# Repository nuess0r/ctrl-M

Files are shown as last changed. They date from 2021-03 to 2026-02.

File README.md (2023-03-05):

# Ctrl M Controller for Model M

ctrl-m

This is a replacement controller for the famous IBM Model M keyboard based on the STM32F072 microcontroller. Goal is to get it upstream in QMK.

Work in progress, prototypes are working in Model M from 1989, there is a bug for the version from 1986 and test for other variants are outstanding.

## Hardware

Controller based on a STM32F072 chip and designed with KiCAD.

To make the controller as flexible as possible there are four possible LED and earth cable connectors. Also the PCB can be cut into a smaller variant that fits the later IBM/Lexmark variant.

The four LED connector variants are:

    J8 is a 12 pin connector is mounted for J8 for both LED and keyboard
    J8 is a 8 pin connector and J9 is a 4 pin connector
    J8 is a 8 pin connector and J12 is a 4 pin connector
    J8 is a 8 pin connector and J10 is a 4 pin header

https://github.com/nuess0r/ctrl-M

To fill the gab between the USB connector and the case and also to make it easier to press the bootloader button a small plastic part (button_lever.amf) was designed with FreeCAD that can be 3D printed.

## Software

https://github.com/nuess0r/qmk_firmware/tree/ctrl_m/keyboards/ctrl_m

## Assembly Instructions

https://brain4free.org/wiki/doku.php/elektronik:ctrl_m#assembly_instructions

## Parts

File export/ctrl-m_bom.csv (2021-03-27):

Comment | Designator | Footprint | LCSC
4.7u | C1,C3 | Capacitor_SMD:C_0805_2012Metric
100n | C2,C4,C5,C6,C7 | Capacitor_SMD:C_0603_1608Metric
10n | C8 | Capacitor_SMD:C_0603_1608Metric
MountingHole_Pad | H1,H2 | MountingHole:MountingHole_3.2mm_M3_Pad
MountingHole | H3,H4 | MountingHole:MountingHole_4mm_Pad
USB_B | J1 | Connector_USB:USB_B_OST_USB-B1HSxx_Horizontal
Conn_01x04 | J10 | Connector_PinHeader_2.54mm:PinHeader_1x04_P2.54mm_Horizontal
Conn_01x05 | J11 | Connector_PinHeader_2.54mm:PinHeader_1x05_P2.54mm_Vertical
Conn_01x04 | J9,J12 | Connector_FPC_2.54mm:TE_5-520315-4_1x04_P2.54mm_Vertical
Conn_ARM_JTAG_SWD_10 | J2 | Connector_PinHeader_1.27mm:PinHeader_2x05_P1.27mm_Vertical
Conn_01x01 | J3,J4,J5,J6 | Connector_Blade:Blade_6.3mm_Horizontal
Conn_01x16 | J7 | Connector_FPC_2.54mm:TE_6-520315-6_1x16_P2.54mm_Vertical
Conn_01x12 | J8 | Connector_FPC_2.54mm:TE_6-520315-2_1x12_P2.54mm_Vertical
1k | R1 | Resistor_SMD:R_0603_1608Metric
120 | R2,R3,R4 | Resistor_SMD:R_0603_1608Metric
SW_Push | SW1 | Button_Switch_THT_narrow:SW_SPST_UK_B0205-G4.3-B-250
USBLC6-2SC6 | U1 | Package_TO_SOT_SMD:SOT-23-6
XC6206P332PR | U2 | Package_TO_SOT_SMD:SOT-89-3
STM32F072CBT6 | U3 | Package_QFP:LQFP-48_7x7mm_P0.5mm

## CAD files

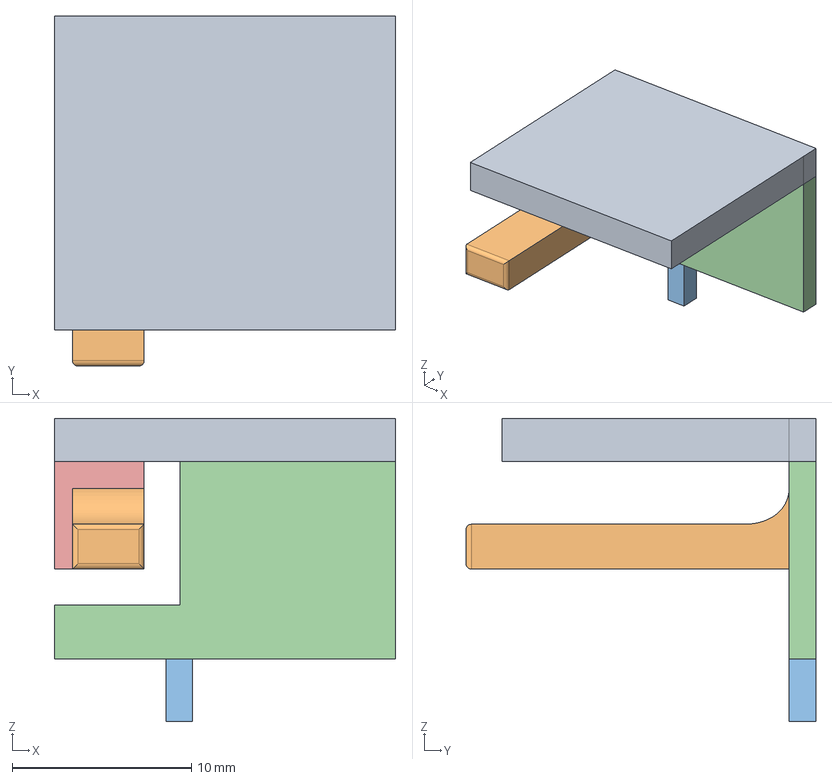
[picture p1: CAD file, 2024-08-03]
export/button_lever.step
19.0 x 19.5 x 16.9 mm

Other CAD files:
button_lever.FCStd
export/button_lever.amf

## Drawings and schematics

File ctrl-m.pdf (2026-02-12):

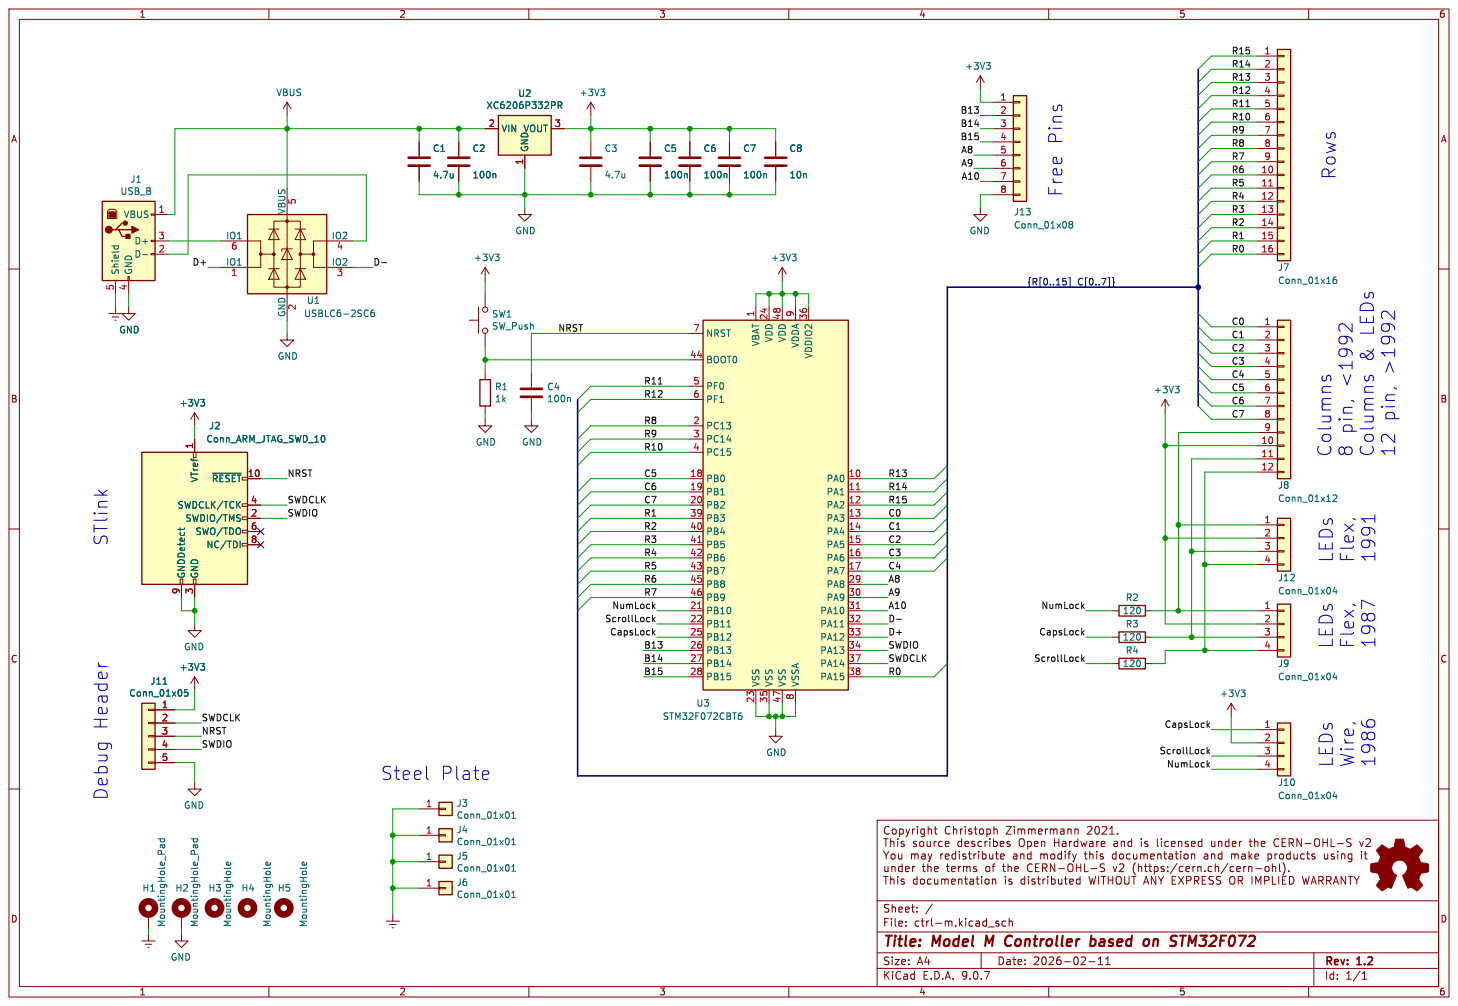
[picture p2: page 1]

& LEDs 12 pin, >1992 LEDs Wire, 1986 Rows Free Pins LEDs Flex, 1991 LEDs Flex, 1987 Debug Header J11 Conn_01x05
B14 STlink

3 ~{RESET}10 SWDCLK/TCK 4 SWDIO/TMS 2 SWO/TDO 6 NC/TDI 8 C2

1 VSS 23 VDD 24 VSS 35 VDD 48 VSS 47 VDDA

3 ~{RESET}10 SWDCLK/TCK 4 SWDIO/TMS 2 SWO/TDO 6 NC/TDI 8

Id: 1/1 Title: Model M Controller based on STM32F072

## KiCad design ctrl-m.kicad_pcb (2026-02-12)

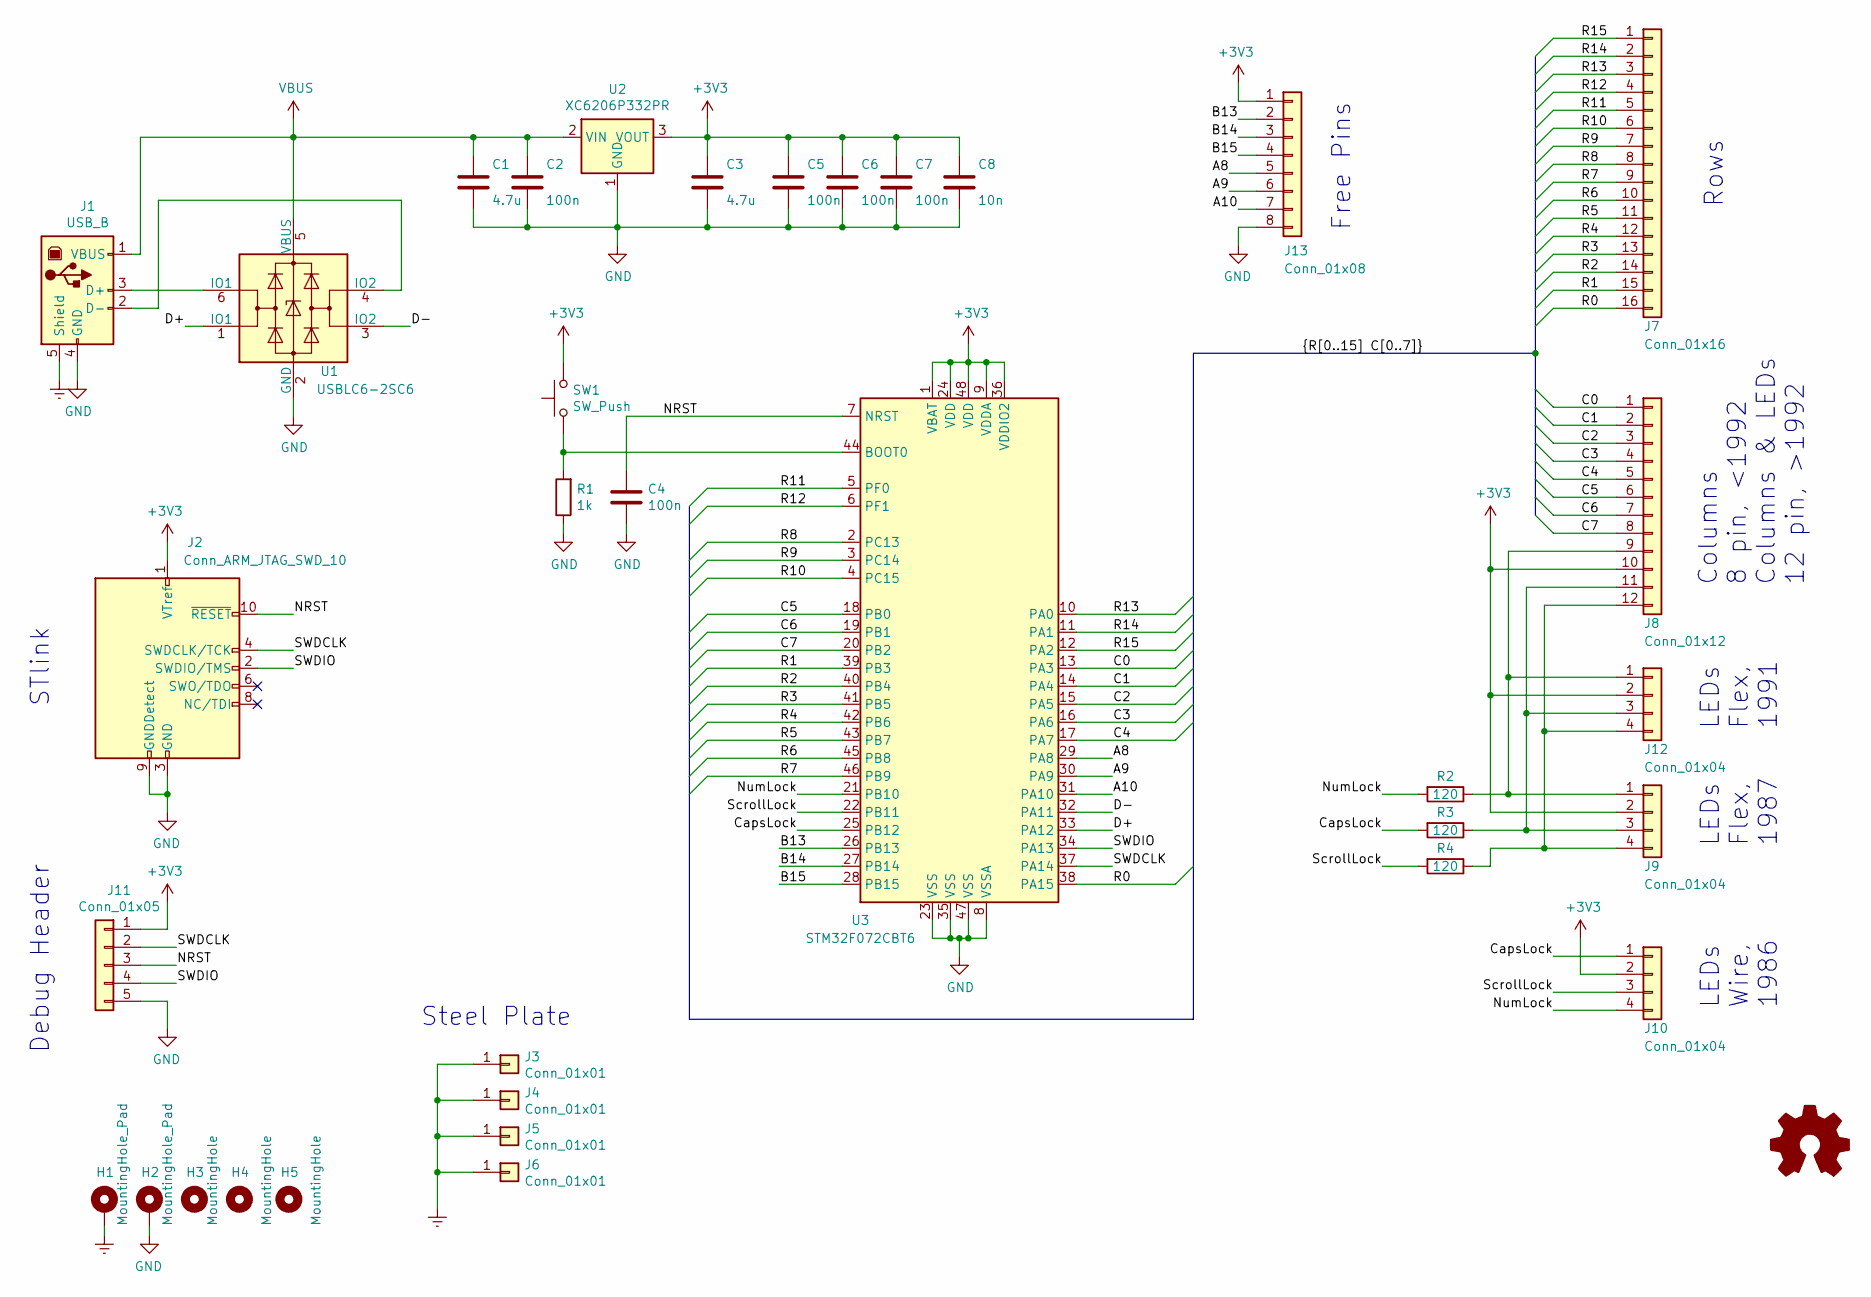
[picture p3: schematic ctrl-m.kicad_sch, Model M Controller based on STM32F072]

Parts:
C1, C3: 4.7u; C_0805_2012Metric
C2, C4, C5, C6, C7: 100n; C_0603_1608Metric
C8: 10n; C_0603_1608Metric
H1, H2: MountingHole_Pad; MountingHole_3.2mm_M3_Pad
H3, H4: MountingHole; MountingHole_4mm_Pad
H5: MountingHole; MountingHole_2.1mm
J1: USB_B; USB_B_OST_USB-B1HSxx_Horizontal
J2: Conn_ARM_JTAG_SWD_10; PinHeader_2x05_P1.27mm_Vertical
J3, J4, J5, J6: Conn_01x01; Blade_6.3mm_Horizontal
J7: Conn_01x16; TE_6-520315-6_1x16_P2.54mm_Vertical
J8: Conn_01x12; TE_6-520315-2_1x12_P2.54mm_Vertical
J9, J12: Conn_01x04; TE_5-520315-4_1x04_P2.54mm_Vertical
J10: Conn_01x04; PinHeader_1x04_P2.54mm_Horizontal
J11: Conn_01x05; PinHeader_1x05_P2.54mm_Vertical
J13: Conn_01x08; PinHeader_1x08_P2.54mm_Vertical
R1: 1k; R_0603_1608Metric
R2, R3, R4: 120; R_0603_1608Metric
SW1: SW_Push; SW_SPST_UK_B0205-G4.3-B-250
U1: USBLC6-2SC6; SOT-23-6
U2: XC6206P332PR; SOT-89-3
U3: STM32F072CBT6; LQFP-48_7x7mm_P0.5mm

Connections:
+3V3: C3.1, C5.1, C6.1, C7.1, C8.1, J2.1 (VTref), J8.10, J9.2, J10.2, J11.1, J12.2, J13.1, SW1.2, U2.3 (VOUT), U3.1 (VBAT), U3.9 (VDDA), U3.24 (VDD), U3.36 (VDDIO2), U3.48 (VDD)
/A8: J13.5, U3.29 (PA8)
/A9: J13.6, U3.30 (PA9)
/A10: J13.7, U3.31 (PA10)
/B13: J13.2, U3.26 (PB13)
/B14: J13.3, U3.27 (PB14)
/B15: J13.4, U3.28 (PB15)
/C0: J8.1, U3.13 (PA3)
/C1: J8.2, U3.14 (PA4)
/C2: J8.3, U3.15 (PA5)
/C3: J8.4, U3.16 (PA6)
/C4: J8.5, U3.17 (PA7)
/C5: J8.6, U3.18 (PB0)
/C6: J8.7, U3.19 (PB1)
/C7: J8.8, U3.20 (PB2)
/CapsLock: J10.1, R3.2, U3.25 (PB12)
/D+: U1.1 (IO1), U3.33 (PA12)
/D-: U1.3 (IO2), U3.32 (PA11)
/NRST: C4.1, J2.10 (~RESET), J11.3, U3.7 (NRST)
/NumLock: J10.4, R2.2, U3.21 (PB10)
/R0: J7.16, U3.38 (PA15)
/R1: J7.15, U3.39 (PB3)
/R2: J7.14, U3.40 (PB4)
/R3: J7.13, U3.41 (PB5)
/R4: J7.12, U3.42 (PB6)
/R5: J7.11, U3.43 (PB7)
/R6: J7.10, U3.45 (PB8)
/R7: J7.9, U3.46 (PB9)
/R8: J7.8, U3.2 (PC13)
/R9: J7.7, U3.3 (PC14)
/R10: J7.6, U3.4 (PC15)
/R11: J7.5, U3.5 (PF0)
/R12: J7.4, U3.6 (PF1)
/R13: J7.3, U3.10 (PA0)
/R14: J7.2, U3.11 (PA1)
/R15: J7.1, U3.12 (PA2)
/SWDCLK: J2.4 (SWDCLK/TCK), J11.2, U3.37 (PA14)
/SWDIO: J2.2 (SWDIO/TMS), J11.4, U3.34 (PA13)
/ScrollLock: J10.3, R4.2, U3.22 (PB11)
Earth: H1.1, J1.5 (Shield), J3.1, J4.1, J5.1, J6.1
GND: C1.2, C2.2, C3.2, C4.2, C5.2, C6.2, C7.2, C8.2, H2.1, J1.4 (GND), J2.3 (GND), J2.5 (GND), J2.9 (GNDDetect), J11.5, J13.8, R1.1, U1.2 (GND), U2.1 (GND), U3.8 (VSSA), U3.23 (VSS), U3.35 (VSS), U3.47 (VSS)
unnamed: J1.3 (D+), U1.6 (IO1)
unnamed: J1.2 (D-), U1.4 (IO2)
unnamed: J8.9, J9.1, J12.1, R2.1
unnamed: J8.11, J9.3, J12.3, R3.1
unnamed: J8.12, J9.4, J12.4, R4.1
unnamed: R1.2, SW1.1, U3.44 (BOOT0)
VBUS: C1.1, C2.1, J1.1 (VBUS), U1.5 (VBUS), U2.2 (VIN)

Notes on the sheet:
LEDs Flex, 1987
LEDs Flex, 1991
Columns 8 pin, <1992 Columns & LEDs 12 pin, >1992
LEDs Wire, 1986
Debug Header
Steel Plate
Rows
Free Pins
STlink

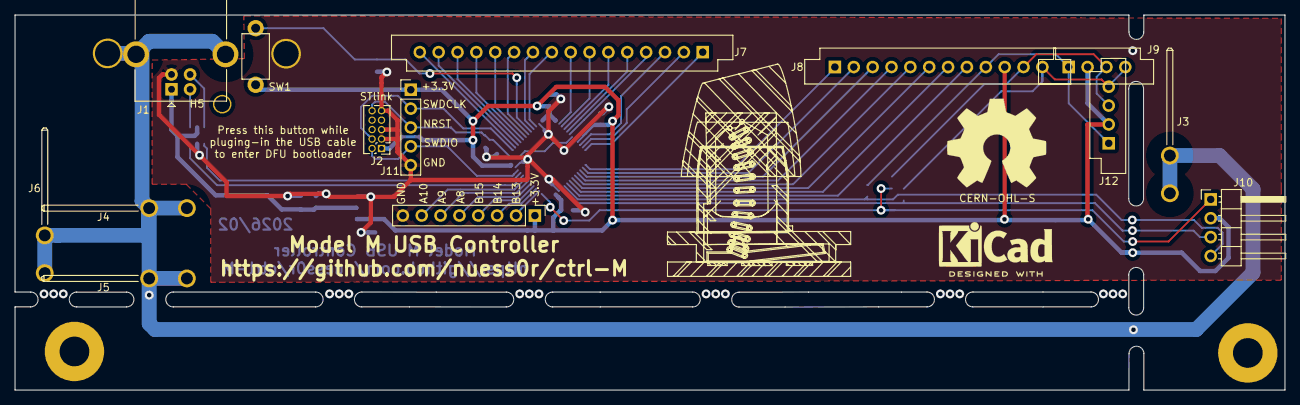
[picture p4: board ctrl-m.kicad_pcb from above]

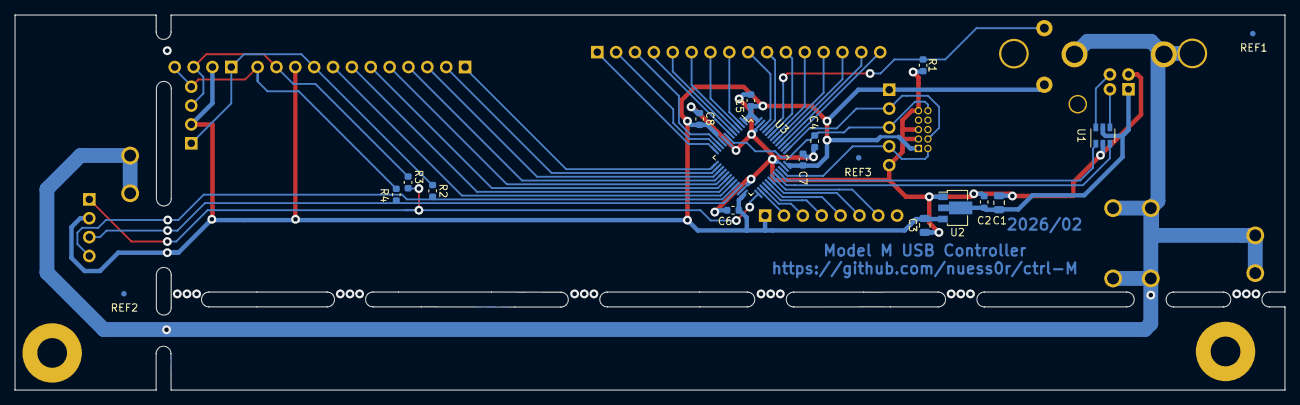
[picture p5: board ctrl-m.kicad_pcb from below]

Board: 2 copper layers, 171.0 x 50.5 mm, 37 parts (18 on the bottom side), 48 nets.

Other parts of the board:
REF1, REF2, REF3: Fiducial_0.75mm_Mask1.5mm

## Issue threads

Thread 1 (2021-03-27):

LD1117 could be unstable with selected capacitors

nuess0r, 2021-03-27:
@mschwingen did a schematic review and one issue was:

> The LD1117 datasheet does not make any notes about stability. Similar
LDOs from other vendors (LM1117 etc.) are known to become unstable with
low-esr (ceramic) output capacitors, so I would guess the LD1117 to
behave similarly. C3 (0805 ceramic) may have a too-low ESR for stable
operation - a 10uF electrolytic or tantalum might be a better choice (or
a LDO that is specified for ceramic output caps - I have used XC6206P33
in other projects, but here are lots of alternatives in SOT-23 available).

nuess0r, 2021-03-27:
Good catch!

According to the AS1117 datasheet (which is the one available as basic part at JLCPCB) an 22 µF tantalum capacitor is recommended to guarantee stability (I have 4.7 µF ceramic).
Also I found the problem that I don't fulfill the minimum load requirement (10 mA) to guarantee voltage regulation when all LEDs are off.

I replaced the LDO now with the XC6206P33PR (SOT-89). The SOT-23 variant should be able to handle the expected heat dissipation but I go for the SOT-89 for more robustness (even if it is a extended part at JLCPCB).

As basic part alternative there is the HT7533-1 but there I found no information in the datasheet about stability and recommended capacitor type. Only that the typical application is with 10 µF. So if someone wants to try, go for it.

Closed 2021-03-27.

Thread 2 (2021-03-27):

Use of PWM-capable pins for LEDs

nuess0r, 2021-03-27:
@mschwingen did a schematic review and one issue was:

> - Pinout. If you shuffle the pins around a bit, you can connect the LEDs
to PWM-capable pins (eg. TIMER3/CH1-3 on PA6, PA7, PB0).

nuess0r, 2021-03-27:
Never cared about something like this. But when I can have it with low effort, why not.

I checked now the QMK firmware about the use of timers (to avoid conflicting with the timer used for the OS scheduler) and how the breathing LED feature is implemented. Turns out, the breathing is using a timer but no PWM capable pin. It's timer assisted software PWM, meaning that the timer fires an interrupt and then the ISR toggles the pin:
https://github.com/qmk/qmk_firmware/blob/master/tmk_core/common/chibios/sleep_led.c

Similar features are available for the audio subsystem. So I will keep the pin-out as it is.

Closed 2021-03-27.

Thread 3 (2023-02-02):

Wrong orientation for wired LED connector

nuess0r, 2023-02-02:
Connector J10 has wrong orientation.
The connector on the cable has a thinner and a thicker side. The plan was, that the thinner side goes to the PCB and misplacing is not possible.
Now J10 is flipped and needs to be bent upwards so the thicker side can go towards the PCB.

nuess0r, 2023-09-21:
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

Closed 2023-05-31.

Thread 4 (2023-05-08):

Mounting holes too tight

nuess0r, 2023-05-08:
The mounting holes next to the USB connector are too tight for some Model M keyboards to easily fit the ctrl-M controller over the plastic pins.

Closed 2023-05-31.

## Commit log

2021-03-24 Initial release
    Ready to order prototypes. Testing is outstanding.
    [ctrl-m-B_Cu.gbr, ctrl-m-B_Mask.gbr, ctrl-m-B_Paste.gbr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]
2021-03-27 Changed LDO type to one that is stable with ceramic capacitors
    LD1117 is unstable with this low output capacitance and in general with
    ceramic capacitors.
    Also it needs 10 mA minimum load which is not guaranteed when all LEDs are off.
    Replaced with a much more recent chip the XC6206P332PR
    [ctrl-m-B_Cu.gbr, ctrl-m-B_Mask.gbr, ctrl-m-B_Paste.gbr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]
2021-07-22 Optimize for production
    Applied design rules of prototype manufacturer
    Fixed DRC errors
    [ctrl-m-B_Cu.gbr, ctrl-m-B_Mask.gbr, ctrl-m-B_Paste.gbr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]
2023-01-19 Add FreeCAD model of a spacer and lever to actuate the button
    The USB connector is less tall than the original connector.
    With this 3D printed part this gap can be filled and also
    a lever is added to push the button.
    [button_lever.FCStd, button_lever.amf]
2023-03-05 Making the button lever more robust
    [button_lever.FCStd, button_lever.amf]
2023-05-31 Fix pinning of J10 in schematic
    And upgrade to KiCAD 6
    [ctrl-m.kicad_sch, ctrl-m.sch]
2023-05-31 Update PCB to wider holes for the plastic pegs and J10 wiring fix
    This solves issue #3 and #4
    [ctrl-m-B_Cu.gbr, ctrl-m-B_Mask.gbr, ctrl-m-B_Paste.gbr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]
2023-05-31 Add STEP file for better compatibility with online shops
    [button_lever.amf, button_lever.step]
2023-07-23 Move button_lever to correct position (change on PCB and 3D model)
    [button_lever.FCStd, button_lever.amf, button_lever.step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]
2023-09-23 Exported button_lever.amf was empty
    [button_lever.amf]
2024-08-03 Modified button lever to be easier to print
    [button_lever.FCStd, button_lever.step]
2026-02-12 Enhancement: have unused pins ending on a pad #8
    Also migrated to KiCAD 9
    [ctrl-m-B_Cu.gbr, ctrl-m-B_Mask.gbr, ctrl-m-B_Paste.gbr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]

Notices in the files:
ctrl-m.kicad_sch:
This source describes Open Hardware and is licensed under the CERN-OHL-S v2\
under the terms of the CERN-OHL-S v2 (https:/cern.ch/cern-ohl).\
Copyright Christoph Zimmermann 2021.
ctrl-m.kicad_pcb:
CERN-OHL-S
